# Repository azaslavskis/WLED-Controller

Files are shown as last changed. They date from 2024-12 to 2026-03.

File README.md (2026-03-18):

# WLED Controller ⚡

A compact ESP32-C3 based controller board for running addressable LED strips with **WLED** and integrating them into **Home Assistant**.

Top view of board

---

## What this project includes

- **Hardware design files** (KiCad project, production outputs, 3D model assets)
- **Firmware patch helper** for building a patched WLED version
- **Assembly references** for the current controller revision

---

## ⚠️ Current hardware status

> **Do not order this PCB revision yet** — the board still has known issues.

### Known issues to fix before ordering

1. `R7` / `EN` pin of `XL1509-5.0V` should be connected to **GND**, not input.
2. ESP32-C3 **pin 9** must be pulled correctly for reliable boot.
3. `DS18B20` pin must be pulled to **3.3V** (fixed on rev **1.6**).
4. More physical spacing is needed for `C1`, `C3`, and `C9`.

---

## Assembled unit

Assembled unit

---

## Build patched firmware

Run the helper script directly:

```bash
wget https://raw.githubusercontent.com/azaslavskis/WLED-Controller/refs/heads/main/software/WLED-Git_patch/patch.sh \
  && chmod +x patch.sh \
  && ./patch.sh
```

---

## Repository layout (high level)

- `hardware/` → PCB project, exports, and fabrication artifacts
- `software/` → firmware patching/build helper files
- `3d-models/` → enclosure and mounting models

---

## Project goal

Create a reliable, DIY-friendly LED controller that is easy to deploy in smart-home setups and flexible enough for custom lighting projects.

## Rework is comming soon

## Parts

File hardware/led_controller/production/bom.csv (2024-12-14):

Designator | Footprint | Quantity | Value | LCSC Part #
C1, C3 | CP_Radial_D5.0mm_P2.50mm | 2 | 470uf
C10, C11, C2, C9 | 1206 | 4 | C
C4, C5 | 1206 | 2 | 0.1uf
C6, C7 | CP_Radial_D5.0mm_P2.50mm | 2 | C_Polarized
C8 | CP_Radial_D7.5mm_P2.50mm | 1 | C_Polarized
D1, D2 | 1206 | 2 | LED
D3, D4 | D_SMA | 2 | SS34
J1 | JST_XH_B4B-XH-AM_1x04_P2.50mm_Vertical | 1 | LED3
J10, J11, J2, J8, J9 | PhoenixContact_MC_1,5_2-G-5.08_1x02_P5.08mm_Horizontal | 5 | POWER
J12 | JST_XH_B4B-XH-AM_1x04_P2.50mm_Vertical | 1 | I2C
J3 | PinHeader_1x03_P2.54mm_Vertical | 1 | LIGHT_SENSOR
J4 | JST_XH_B4B-XH-AM_1x04_P2.50mm_Vertical | 1 | LED_1
J5 | JST_XH_B4B-XH-AM_1x04_P2.50mm_Vertical | 1 | USB
J6 | PinHeader_1x04_P2.54mm_Vertical | 1 | OLED
J7 | PinHeader_1x04_P2.54mm_Vertical | 1 | FLASH
L1 | L_Coilcraft_XAL8050-223 | 1 | L
Q1, Q2, Q3, Q4 | TO-252-2_L6.6-W6.1-P4.58-LS9.9-TL | 4 | IRLR8726TRPBF | C81137
R1, R14, R15, R17, R18, R19, R2, R20, R4, R6, R7 | 1206 | 11 | 22R
R10, R12, R8 | 1206 | 3 | 1K
R11, R13, R16, R9 | 1206 | 4 | 10K
R21 | 2512 | 1 | R
R22, R23 | 1206 | 2 | R
R3, R5 | 1206 | 2 | 220R
U1 | SOIC-8_3.9x4.9mm_P1.27mm | 1 | XL1509-5.0
U2 | SOT-223-3_TabPin2 | 1 | AMS1117-3.3
U3 | ESP32-C3-WROOM-02U | 1 | ESP32-C3-WROOM-02
U4, U7 | DBV5 | 2 | SN74AHC1G32DBVR
U5 | SOIC-8_3.9x4.9mm_P1.27mm | 1 | CH330N
U6 | SOIC-8_3.9x4.9mm_P1.27mm | 1 | DS18B20Z
U8 | SOIC-8_3.9x4.9mm_P1.27mm | 1 | INA219AxD

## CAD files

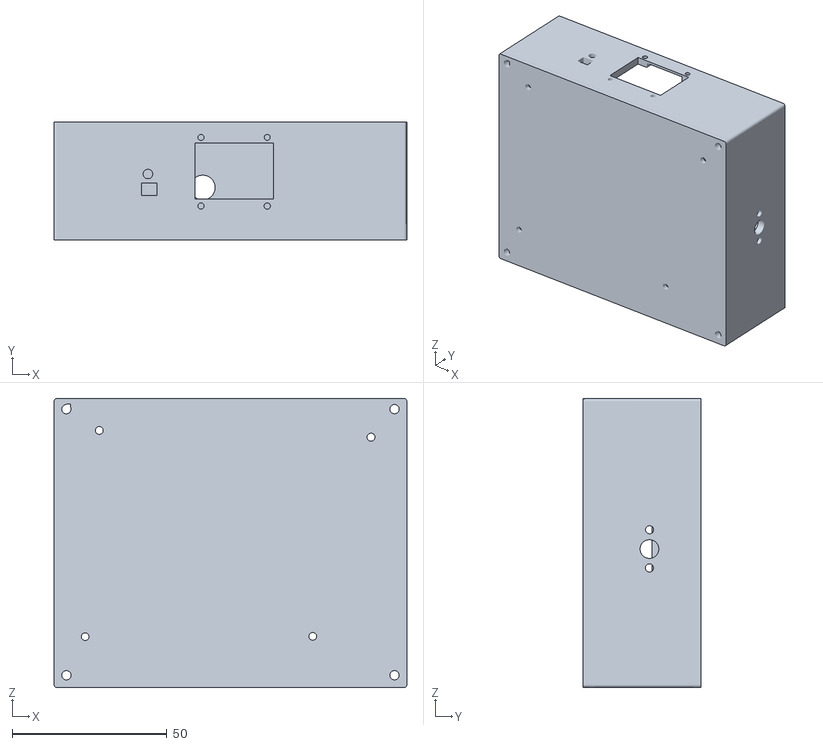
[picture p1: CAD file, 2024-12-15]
3d-models/main part.stl
114.1 x 38.0 x 93.5

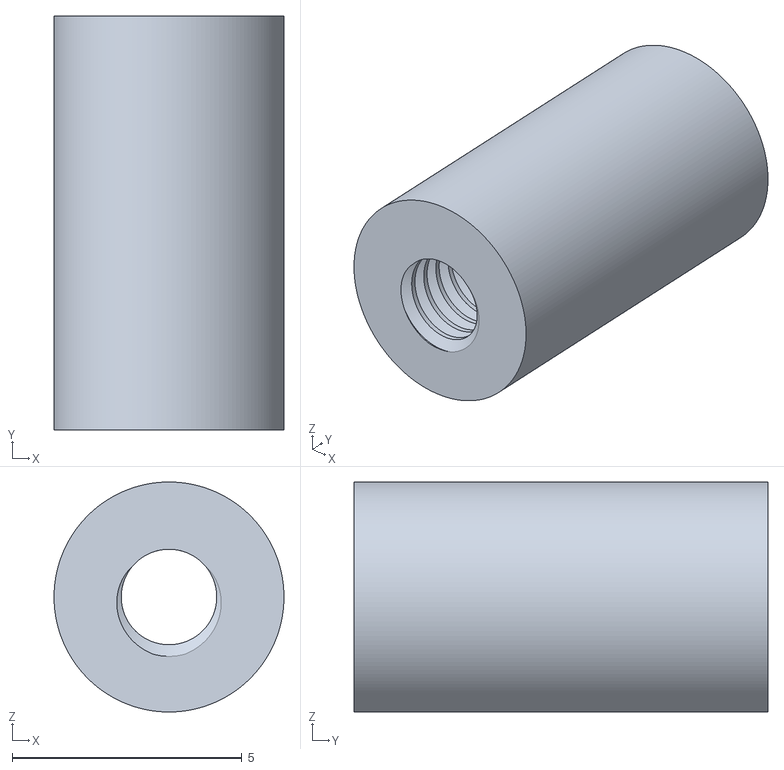
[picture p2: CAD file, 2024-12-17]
3d-models/stands.stl
5.00 x 9.00 x 5.00

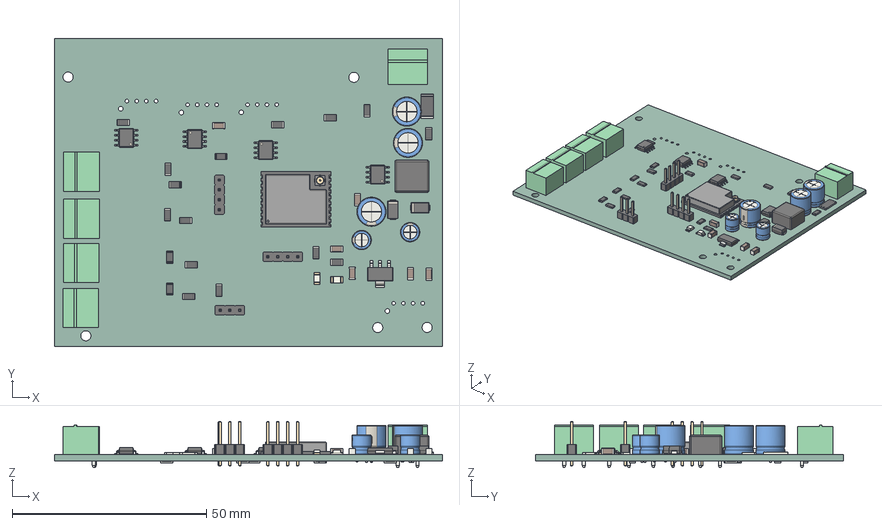
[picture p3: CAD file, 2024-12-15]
hardware/led_controller/led_controller.step
99.9 x 79.3 x 11.9 mm
D_SMA x 2
C_1206_3216Metric x 6
MC_01x02_G_5_08mm x 5
LED_1206_3216Metric x 2
CP_Radial_D50mm_P250mm x 2
PinHeader_1x04_P254mm_Vertical x 2
R_1206_3216Metric x 23
CP_Radial_D75mm_P250mm x 3
SOIC_8_39x49mm_P127mm x 4
R_2512_6332Metric
CQ assembly
SOT_223
PinHeader_1x03_P254mm_Vertical
ESP32-C3-WROOM-02U
led_controller_PCB

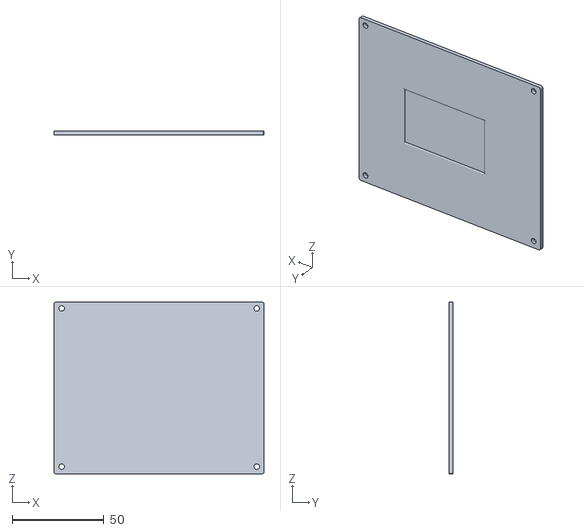
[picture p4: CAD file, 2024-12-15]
3d-models/cover.stl
114.2 x 2.00 x 93.4

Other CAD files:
3d-models/led controller v10.f3z

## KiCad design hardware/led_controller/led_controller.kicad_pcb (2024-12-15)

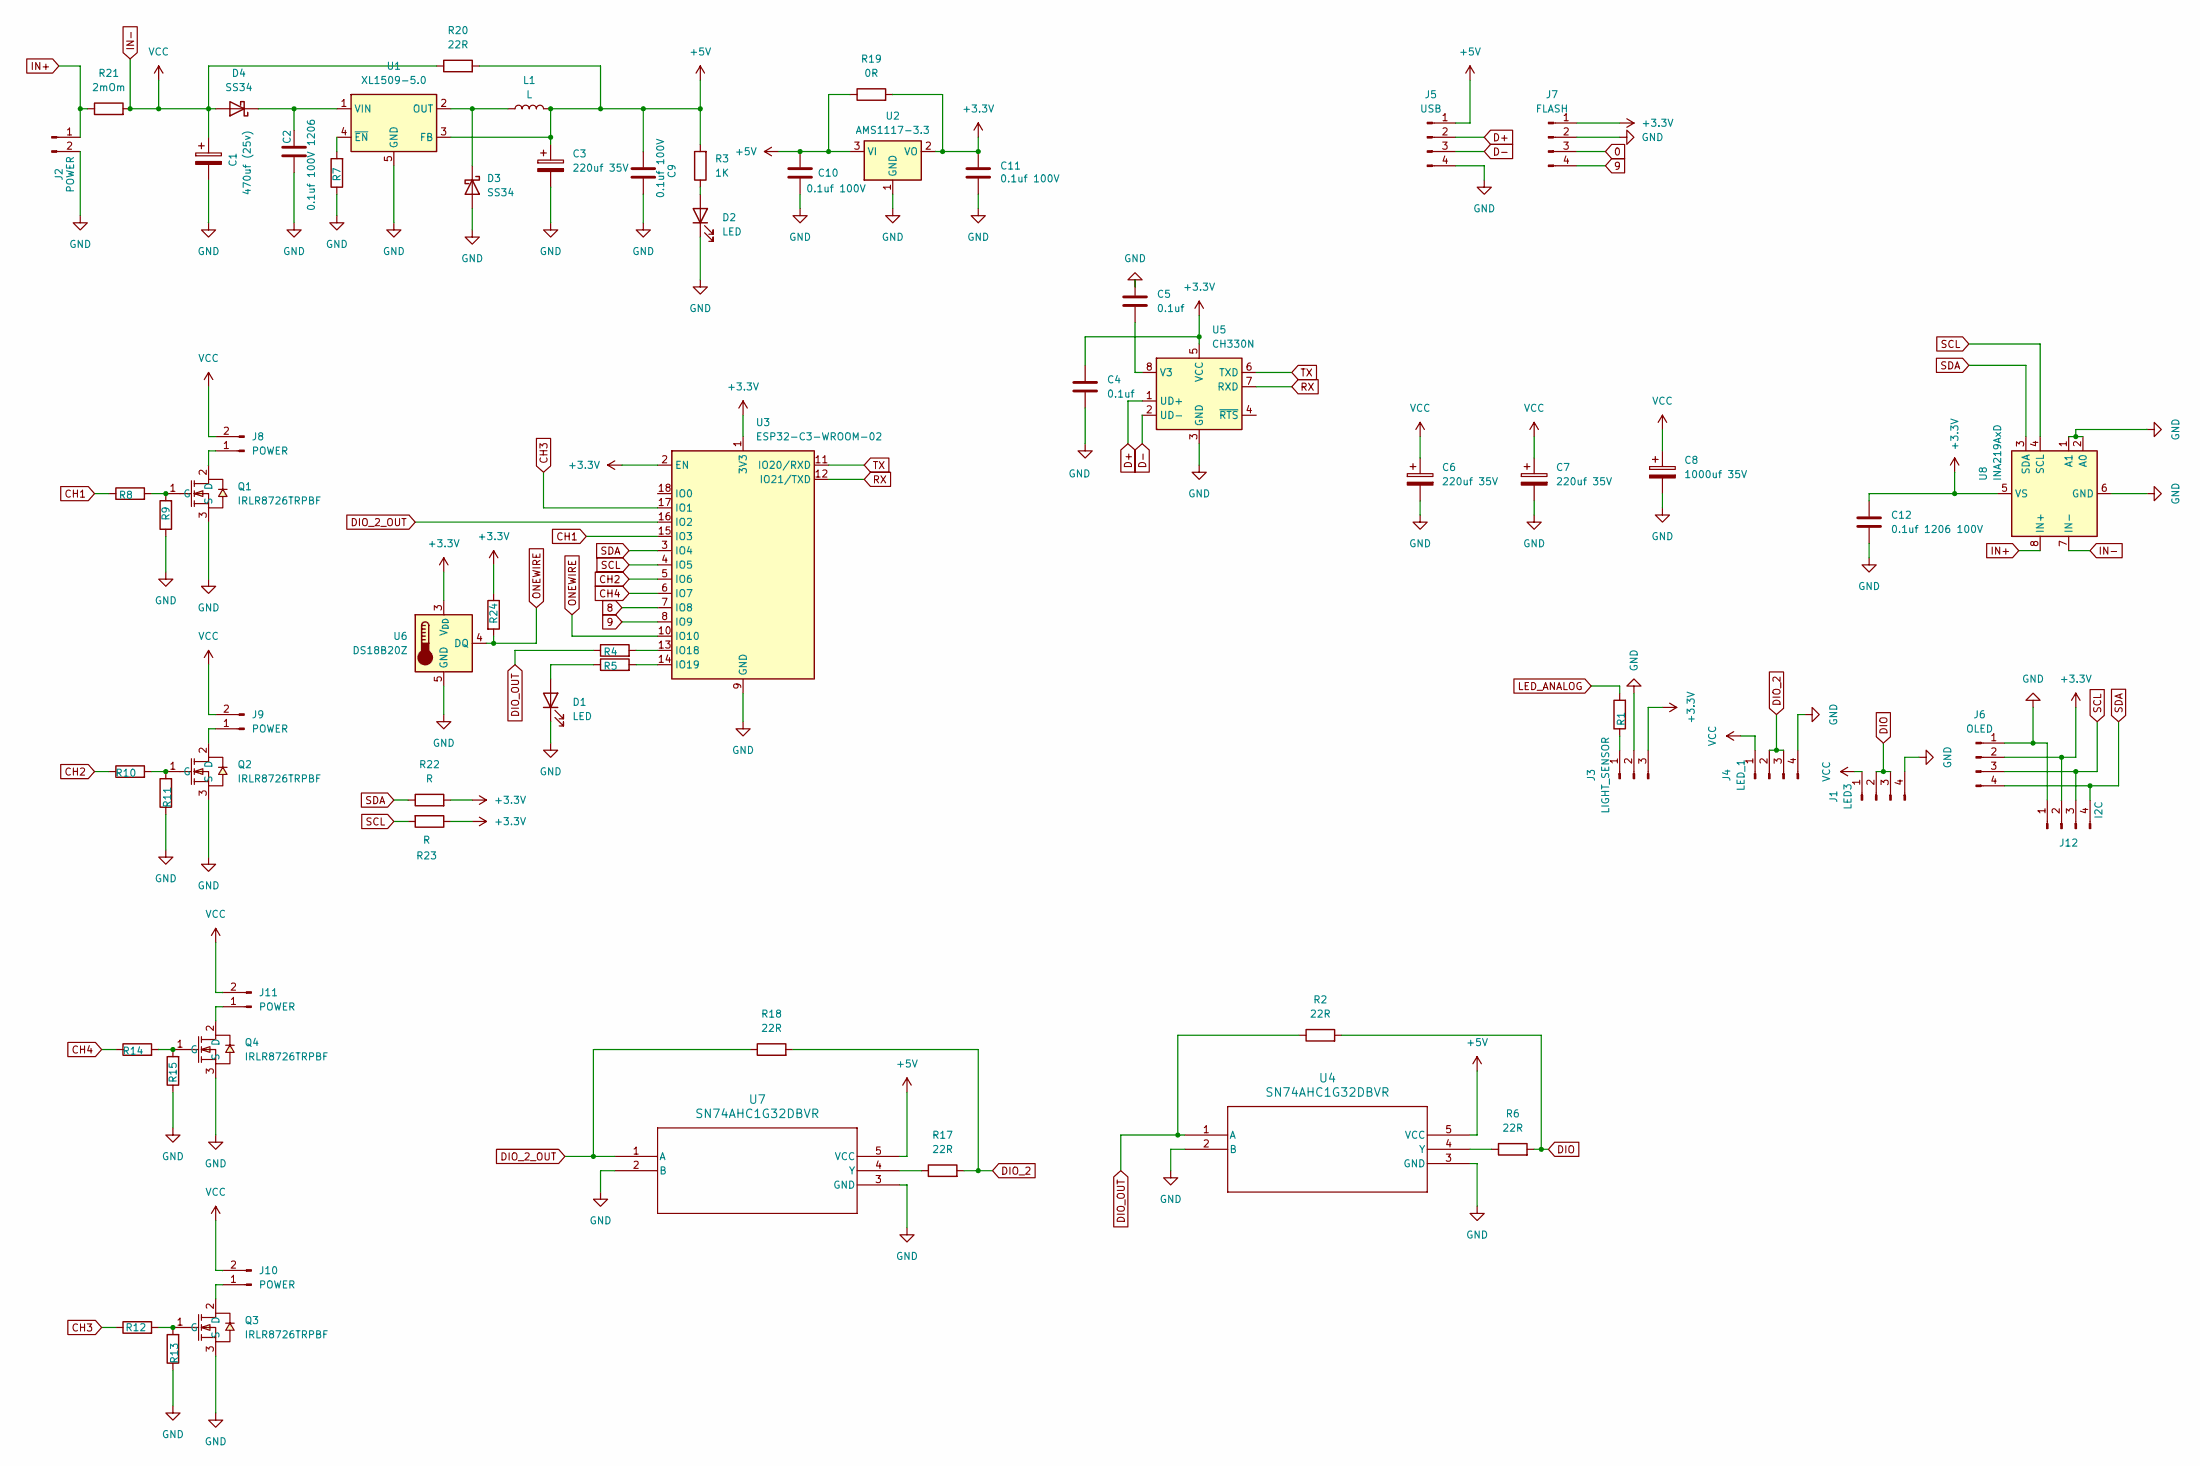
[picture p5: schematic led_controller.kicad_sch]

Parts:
C1: 470uf (25v); CP_Radial_D7.5mm_P2.50mm
C2: 0.1uf 100V 1206; C_1206_3216Metric
C3: 220uf 35V; CP_Radial_D7.5mm_P2.50mm
C4, C5: 0.1uf; C_1206_3216Metric
C6, C7: 220uf 35V; CP_Radial_D5.0mm_P2.50mm
C8: 1000uf 35V; CP_Radial_D7.5mm_P2.50mm
C9, C10, C11: 0.1uf 100V; C_1206_3216Metric
C12: 0.1uf 1206 100V; R_1206_3216Metric
D1, D2: LED; LED_1206_3216Metric
D3, D4: SS34; D_SMA
J1: LED3; JST_XH_B4B-XH-AM_1x04_P2.50mm_Vertical
J2, J8, J9, J10, J11: POWER; PhoenixContact_MC_1,5_2-G-5.08_1x02_P5.08mm_Horizontal
J3: LIGHT_SENSOR; PinHeader_1x03_P2.54mm_Vertical
J4: LED_1; JST_XH_B4B-XH-AM_1x04_P2.50mm_Vertical
J5: USB; JST_XH_B4B-XH-AM_1x04_P2.50mm_Vertical
J6: OLED; PinHeader_1x04_P2.54mm_Vertical
J7: FLASH; PinHeader_1x04_P2.54mm_Vertical
J12: I2C; JST_XH_B4B-XH-AM_1x04_P2.50mm_Vertical
L1: L; L_Coilcraft_XAL8050-223
Q1, Q2, Q3, Q4: IRLR8726TRPBF; TO-252-2_L6.6-W6.1-P4.58-LS9.9-TL; LCSC Part C81137
R1, R2, R4, R6, R7, R15, R17, R18, R20: 22R; R_1206_3216Metric
R3: 1K; R_1206_3216Metric
R5, R8, R10, R12, R14: 220R; R_1206_3216Metric
R9, R11, R13, R24: 10K; R_1206_3216Metric
R19: 0R; R_1206_3216Metric
R21: 2mOm; R_2512_6332Metric
R22, R23: R; R_1206_3216Metric
U1: XL1509-5.0; SOIC-8_3.9x4.9mm_P1.27mm
U2: AMS1117-3.3; SOT-223-3_TabPin2
U3: ESP32-C3-WROOM-02; ESP32-C3-WROOM-02U
U4, U7: SN74AHC1G32DBVR; DBV5
U5: CH330N; SOIC-8_3.9x4.9mm_P1.27mm
U6: DS18B20Z; SOIC-8_3.9x4.9mm_P1.27mm
U8: INA219AxD; SOIC-8_3.9x4.9mm_P1.27mm

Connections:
0: J7.3, U3.18 (IO0)
+3.3V: C4.1, C11.1, C12.2, J3.3, J6.2, J7.1, J12.2, R19.2, R22.2, R23.1, R24.1, U2.2 (VO), U3.1 (3V3), U3.2 (EN), U5.5 (VCC), U6.3 (V_{DD}), U8.5 (VS)
+5V: C3.1, C9.1, C10.1, J5.1, L1.2, R3.2, R19.1, R20.2, U1.3 (FB), U2.3 (VI), U4.5 (VCC), U7.5 (VCC)
CH1: R8.1, U3.15 (IO3)
CH2: R10.1, U3.5 (IO6)
CH4: R14.1, U3.6 (IO7)
D+: J5.2, U5.1 (UD+)
D-: J5.3, U5.2 (UD-)
DIO: J1.2, J1.3, R2.2, R6.2
DIO_2: J4.2, J4.3, R17.2, R18.2
DIO_2_OUT: R18.1, U3.16 (IO2), U7.1 (A)
DIO_OUT: R2.1, R4.1, U4.1 (A)
GND: C1.2, C2.2, C3.2, C4.2, C5.1, C6.2, C7.2, C8.2, C9.2, C10.2, C11.2, C12.1, D1.1 (K), D2.1 (K), D3.2 (A), J1.4, J2.2, J3.2, J4.4, J5.4, J6.1, J7.2, J12.1, Q1.3 (S), Q2.3 (S), Q3.3 (S), Q4.3 (S), R7.1, R9.1, R11.1, R13.1, R15.1, U1.5 (GND), U1.6 (GND), U1.7 (GND), U1.8 (GND), U2.1 (GND), U3.9 (GND), U3.19 (GND), U4.2 (B), U4.3 (GND), U5.3 (GND), U6.5 (GND), U7.2 (B), U7.3 (GND), U8.1 (A1), U8.2 (A0), U8.6 (GND)
IN+: J2.1, R21.1, U8.8 (IN+)
IN-: C1.1, C6.1, C7.1, C8.1, D4.2 (A), J1.1, J4.1, J8.2, J9.2, J10.2, J11.2, R20.1, R21.2, U8.7 (IN-)
unnamed: D1.2 (A), R5.1
unnamed: D2.2 (A), R3.1
unnamed: D3.1 (K), L1.1, U1.2 (OUT)
unnamed: C2.1, D4.1 (K), U1.1 (VIN)
unnamed: J3.1, R1.1
unnamed: J8.1, Q1.2 (D)
unnamed: J9.1, Q2.2 (D)
unnamed: J10.1, Q3.2 (D)
unnamed: J11.1, Q4.2 (D)
unnamed: Q1.1 (G), R8.2, R9.2
unnamed: Q2.1 (G), R10.2, R11.2
unnamed: Q3.1 (G), R12.2, R13.2
unnamed: Q4.1 (G), R14.2, R15.2
unnamed: R7.2, U1.4 (~EN)
unnamed: R4.2, U3.13 (IO18)
unnamed: R5.2, U3.14 (IO19)
unnamed: R6.1, U4.4 (Y)
unnamed: C5.2, U5.8 (V3)
unnamed: R17.1, U7.4 (Y)
ONEWIRE: R24.2, U3.10 (IO10), U6.4 (DQ)
RX: U3.12 (IO21/TXD), U5.7 (RXD)
SCL: J6.3, J12.3, R23.2, U3.4 (IO5), U8.4 (SCL)
SDA: J6.4, J12.4, R22.1, U3.3 (IO4), U8.3 (SDA)
TX: U3.11 (IO20/RXD), U5.6 (TXD)

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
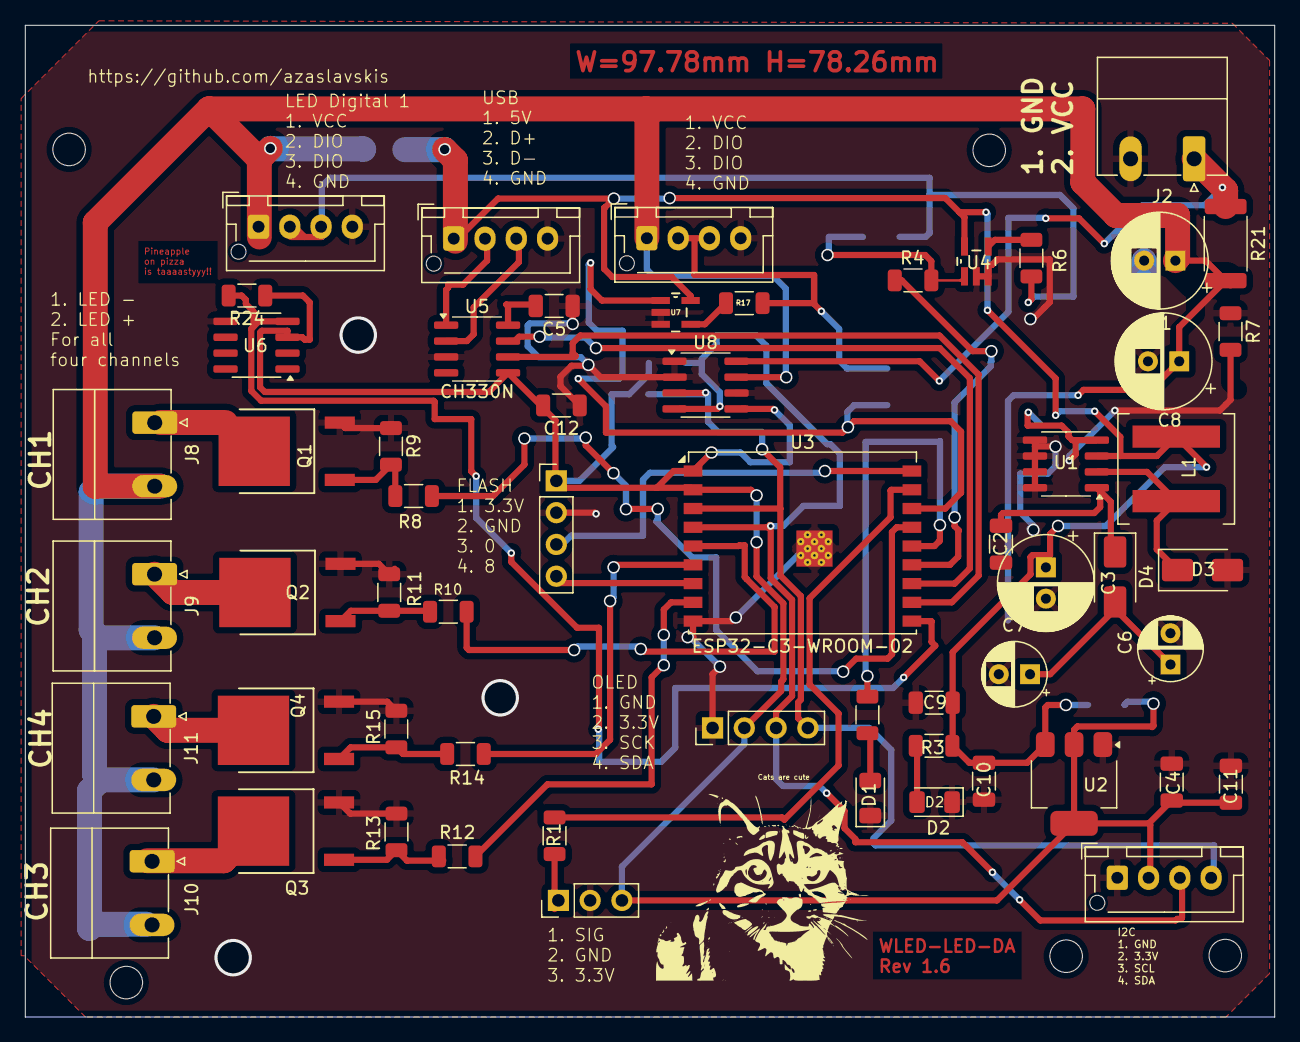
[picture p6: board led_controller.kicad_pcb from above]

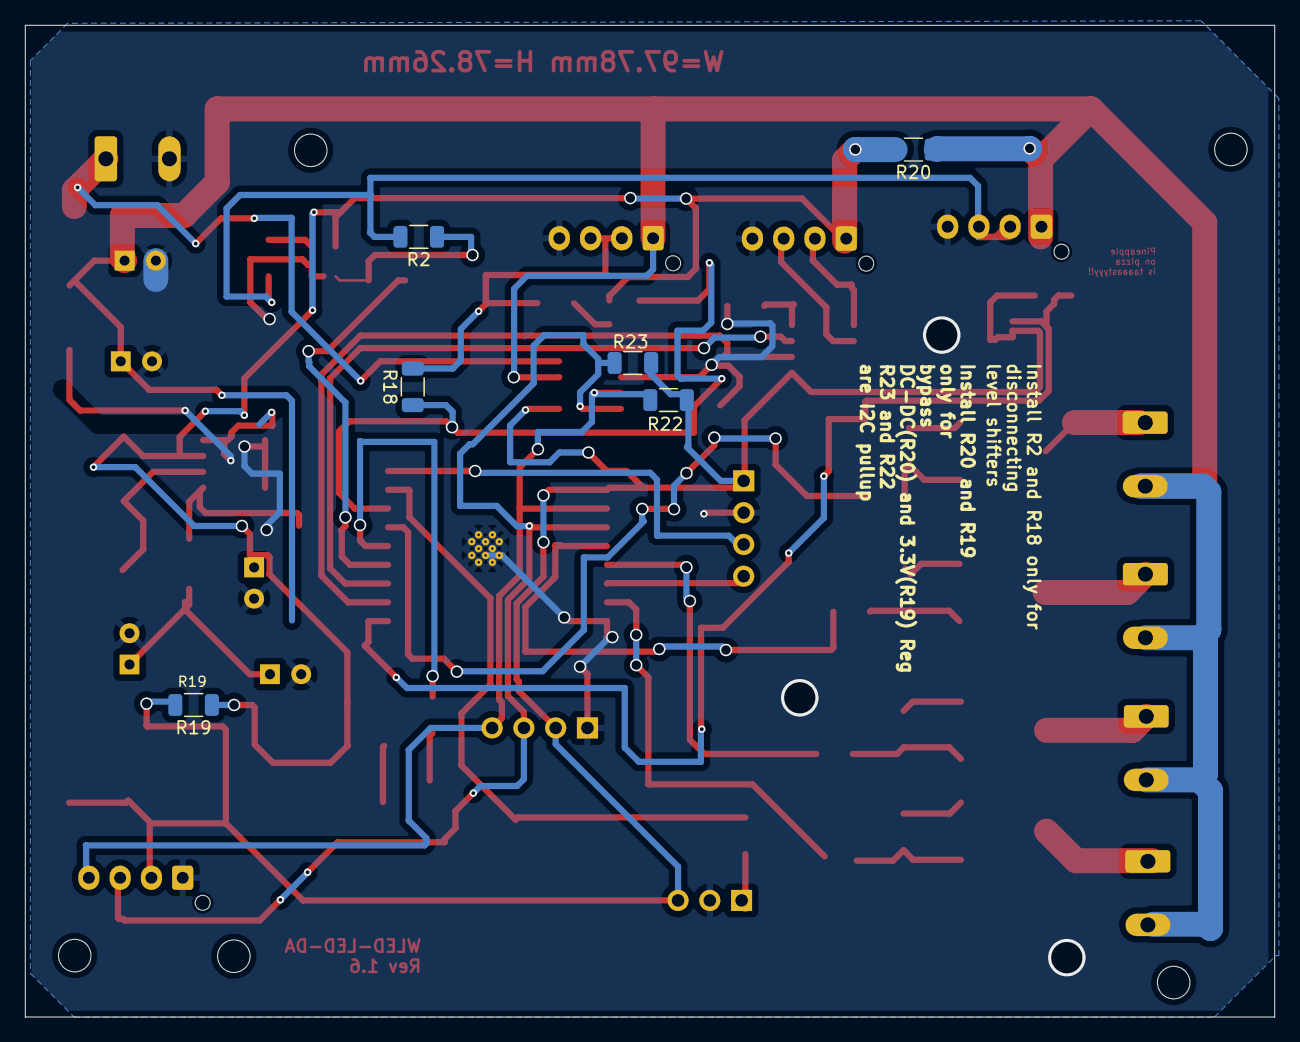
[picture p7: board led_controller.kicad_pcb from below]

Board: 2 copper layers, 99.9 x 79.3 mm, 64 parts (6 on the bottom side), 42 nets.

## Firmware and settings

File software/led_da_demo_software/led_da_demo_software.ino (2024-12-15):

#include <ESP32_WS2812_Lib.h>
#include <INA219.h>
#include <DS18B20.h>
#include <Wire.h>
#include <Adafruit_GFX.h>
#include <Adafruit_SSD1306.h>

// Pin Definitions
#define SDA_PIN 4      // I2C SDA Pin
#define SCL_PIN 5      // I2C SCL Pin
#define ONE_WIRE_PIN 10 // OneWire data pin for DS18B20 sensors
#define LEDS_COUNT 8    // Number of LEDs in the WS2812 strip
#define LEDS_PIN 2      // Pin for WS2812 LED strip
#define CHANNEL 0       // LED channel for ESP32
#define SCREEN_WIDTH 128  // OLED display width, in pixels
#define SCREEN_HEIGHT 64  // OLED display height, in pixels
#define OLED_RESET -1     // Reset pin # (or -1 if sharing Arduino reset pin)
#define SCREEN_ADDRESS 0x3C  // Address for 128x64 OLED

// Global Objects
DS18B20 ds(ONE_WIRE_PIN);                        // Initialize DS18B20 sensor on the defined pin
ESP32_WS2812 strip = ESP32_WS2812(LEDS_COUNT, LEDS_PIN, CHANNEL, TYPE_GRB); // WS2812 LED strip object
INA219 INA(0x40);                               // INA219 power sensor object
Adafruit_SSD1306 display(SCREEN_WIDTH, SCREEN_HEIGHT, &Wire, OLED_RESET); // OLED display object

void setup() {
  // Initialize Serial Communication
  Serial.begin(115200);
  Serial.println("[DEBUG] Serial initialized");

  // Initialize I2C
  Wire.setPins(SDA_PIN, SCL_PIN);
  Wire.begin();
  Serial.println("[DEBUG] I2C initialized");

  // Initialize INA219 Sensor
  if (!INA.begin()) {
    Serial.println("[ERROR] INA219 initialization failed");
  } else {
    INA.setMaxCurrentShunt(5, 0.02); // Configure shunt resistor
    Serial.println("[DEBUG] INA219 configured");
  }

  // Initialize OneWire DS18B20 Sensor
  Serial.println("[DEBUG] Scanning OneWire sensors...");
  int numDevices = ds.getNumberOfDevices(); // Scan for DS18B20 devices
  Serial.print("Devices found: ");
  Serial.println(numDevices);

  // Initialize OLED Display
  if (!display.begin(SSD1306_SWITCHCAPVCC, SCREEN_ADDRESS)) {
    Serial.println("[ERROR] SSD1306 initialization failed");
    for (;;); // Halt execution if OLED initialization fails
  }
  display.display();  // Show splash screen
  delay(2000);        // Pause for 2 seconds
  display.clearDisplay();
  Serial.println("[DEBUG] OLED initialized");

  // Draw initial pixel on the display
  display.drawPixel(10, 10, SSD1306_WHITE);
  display.display();
}

void loop() {
  // Log INA219 Voltage and Current Readings
  Serial.println("[INFO] INA219 Readings:");
  Serial.print("Voltage: ");
  Serial.print(INA.getBusVoltage());
  Serial.print(" V, Current: ");
  Serial.print(INA.getCurrent_mA());
  Serial.println(" mA");

  // Log Number of OneWire Sensors
  Serial.print("[INFO] DS18B20 Sensors Found: ");
  Serial.println(ds.getNumberOfDevices());

  // Blink an LED on pin 3
  digitalWrite(3, HIGH);
  delay(1000);
  digitalWrite(3, LOW);
  delay(1000);

  // Update WS2812 LED Strip
  strip.setBrightness(0);          // Set brightness to minimum
  strip.setAllLedsColor(0, 0, 255); // Set all LEDs to blue
  strip.show();
  delay(1000);                     // Wait for 1 second

  strip.setBrightness(255);        // Set brightness to maximum
  strip.setAllLedsColor(0, 0, 255); // Keep LEDs blue
  strip.show();
  delay(1000);

  // Display Temperature Reading on OLED
  if (ds.getNumberOfDevices() > 0) {
    float temperature = ds.getTempC();
    display.clearDisplay();
    display.setTextSize(1);
    display.setTextColor(SSD1306_WHITE);
    display.setCursor(0, 0);
    display.print("Temperature: ");
    display.print(temperature);
    display.print(" C");
    display.display();
  } else {
    display.clearDisplay();
    display.setCursor(0, 0);
    display.setTextSize(1);
    display.setTextColor(SSD1306_WHITE);
    display.print("No DS18B20 sensors found");
    display.display();
  }

  delay(1000);  // Wait 1 second before next loop iteration
}

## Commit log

2024-12-02 append and PCB boards design
    [xmas_both.kicad_pcb]
2024-12-14 added last pcb verison
    [bom.csv, designators.csv, led_controller.kicad_pcb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]
2024-12-14 added pcb issues log README.md
2024-12-15 added wled patch file
    [led_controller.step]
2024-12-15 add 3d parts
    [controller.f3z, cover.stl, led_controller.kicad_pcb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]
2024-12-17 appended last version of controller case
    [controller.f3z, led controller v10.f3z, stands.stl]
